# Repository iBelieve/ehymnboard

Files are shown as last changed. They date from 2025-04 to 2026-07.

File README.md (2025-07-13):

# eHymnBoard

A digital hymn board using e-ink screens. Designed and built by Michael Spencer and Christopher Spencer. First used in the Divine Service on Easter Sunday, A+D 2025.

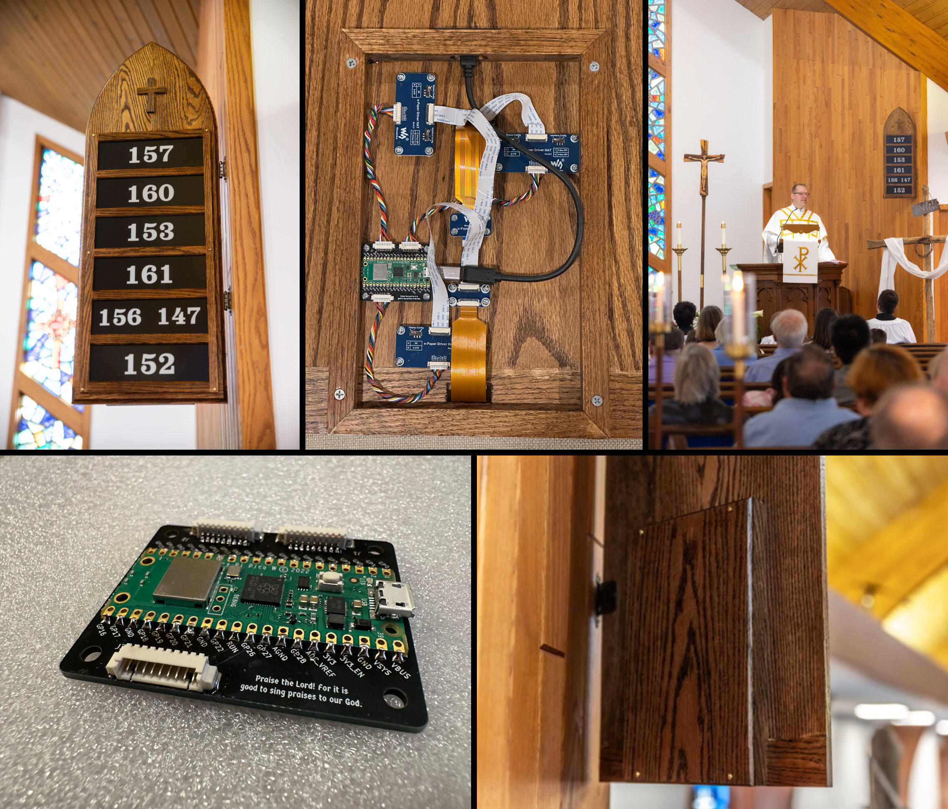
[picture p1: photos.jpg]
Photos of the hymn board


This was a really interesting opportunity to explore how we might leverage modern technology in an anti-technology, anti-screens way. Hymn boards are a beautiful contrast to the modern trend of putting big distracting glowing screens in the front of the sanctuary by directing the congregation to a hymnal, a physical book with a collection of beloved time-tested hymns, a book that belongs not just in the sanctuary but in the home for daily family devotions.

The e-ink is as minimally distracting as possible. The screens have no light and do not glow at all; the e-ink particles combined with a matte finish makes them look "real" and "physical" and not digital or screen-like.They are updated once before the service and are literally powered off for the entire duration of the service (due to its physical nature, e-ink "holds" its content without power).

Looking for other projects that explore how modern technology can enhance tradition? Check out the [St. Martin Luther Zimbelstern](https://github.com/cmspencer109/Zimbelstern) by Christopher Spencer.

### Project Parts and Tech Stack

**Device**

The on-device code is responsible for driving the e-ink screens and handling the network communication with the server.

- Raspberry Pi Pico W
- [3x Waveshare 13.3" E-Paper HAT (K)](https://www.waveshare.com/product/ai/displays/e-paper/13.3inch-e-paper-hat-k.htm)
- Pico SDK
- C++

**Server**

The web app and backend for the eHymnBoard project.

- Python 3
- Flask
- Tailwind CSS
- daisyUI

Code is deployed to a [Hetzner VPS](https://www.hetzner.com/cloud/) using [Dokku](https://dokku.com).

**PCB Designs**

Custom PCBs that add picoblade connectors to the Pi Pico for the e-ink screens to connect to.

- KiCad 6

**CAD Designs**

CAD designs for the actual wood hymn board, the routing jig, and 3D printed standoffs for mounting all the circuit boards in the enclosure.

[OnShape CAD designs](https://cad.onshape.com/documents/b7beeccbdc2f765f30134b80/w/63d45aaa309ee02d139aa6aa/e/1ed80022fc77088e67dab883)

### Suppliers

No affiliation or sponsorship, just good suppliers we found.

- [Waveshare](https://www.waveshare.com/) - E-ink screens
- [DigiKey](https://www.digikey.com/) - Electronic components
- [JLCPCB](https://jlcpcb.com/) - PCB manufacturing
- [Woodchucks Wood](https://woodchuckswood.com/) - Wood for the boards

### License

- The device code is licensed under the [GNU General Public License v3.0 or later](https://www.gnu.org/licenses/gpl-3.0.en.html).
- The server code is licensed under the [GNU Affero General Public License v3.0 or later](https://www.gnu.org/licenses/agpl-3.0.en.html).
- The CAD models and PCB designs are licensed under the [CERN Open Hardware License v2 - Strongly Reciprocal](https://gitlab.com/ohwr/project/cernohl/-/wikis/uploads/819d71bea3458f71fba6cf4fb0f2de6b/cern_ohl_s_v2.txt).

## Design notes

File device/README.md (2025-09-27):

# eHymnBoard Device Firmware

### Pico SDK

See documentation at https://datasheets.raspberrypi.com/pico/raspberry-pi-pico-c-sdk.pdf

Make sure you install the Raspberry Pi Pico SDK.

### WiFi Configuration

Copy `secrets.example.h` to `secrets.h` and replace the example config with one or more WiFi SSID and passphrase entries.

### Compiling

First create the build directory:

```sh
cmake -G Ninja -B build
```

Then cd into the build directory and run:

```sh
ninja
```

To flash the Pico:

```sh
picotool load -xf ehymnboard.elf
```

### Monitoring Output

You can monitor the serial output from the Pico using the included monitor script. It depends on `pyserial`, installable via pip. It will automatically detect the right serial device on macOS. Modify as needed for other platforms.

```sh
./monitor.py
```

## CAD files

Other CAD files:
hardware/KiCad-RP-Pico/SketchUp Model/Pico.skp

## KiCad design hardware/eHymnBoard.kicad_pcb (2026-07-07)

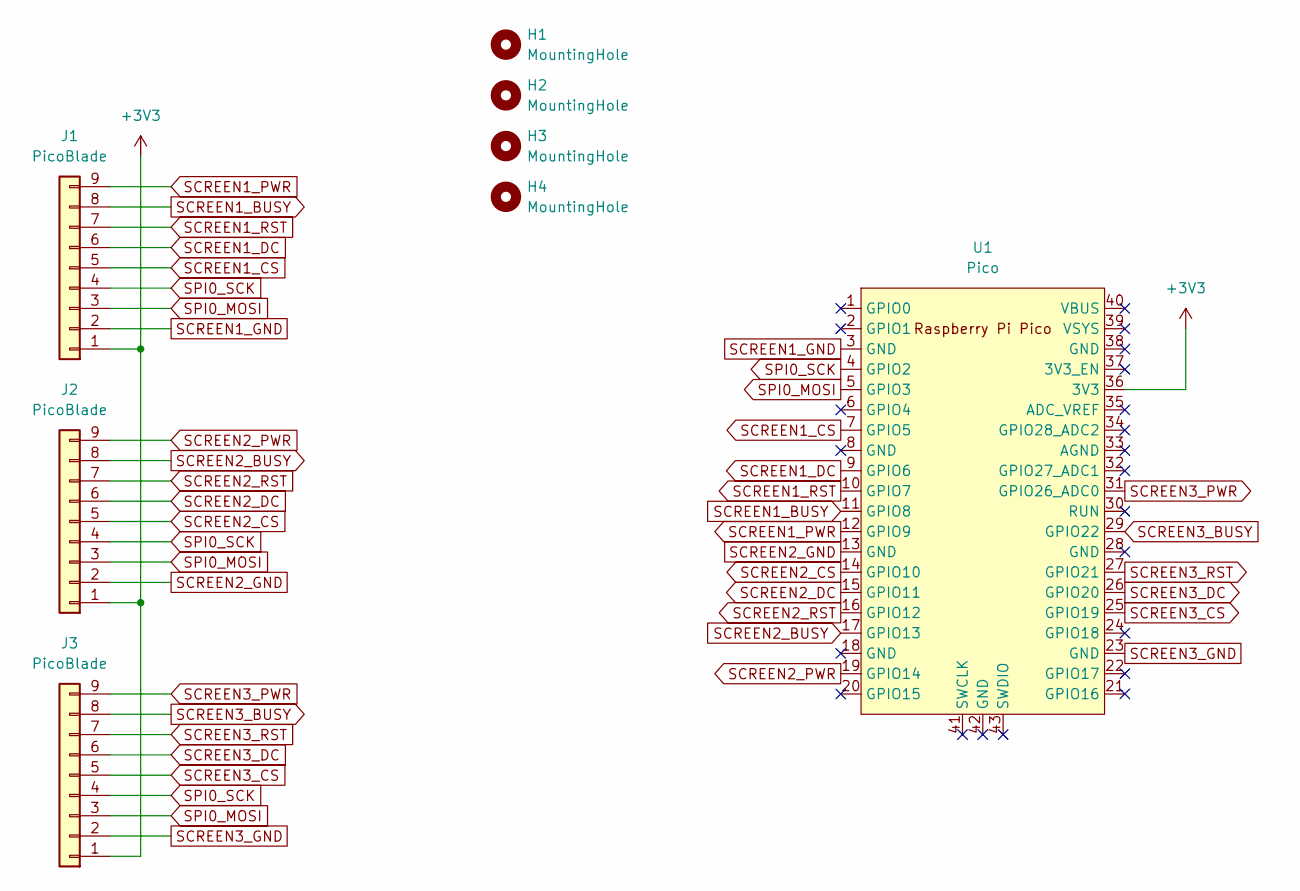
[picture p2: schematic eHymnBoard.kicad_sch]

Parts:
H1, H2, H3, H4: MountingHole; MountingHole_3mm
J1, J2, J3: PicoBlade; Molex_PicoBlade_53261-0971_1x09-1MP_P1.25mm_Horizontal
U1: Pico; RPi_Pico_SMD_TH

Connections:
+3V3: J1.1, J2.1, J3.1, U1.36 (3V3)
SCREEN1_BUSY: J1.8, U1.11 (GPIO8)
SCREEN1_CS: J1.5, U1.7 (GPIO5)
SCREEN1_DC: J1.6, U1.9 (GPIO6)
SCREEN1_GND: J1.2, U1.3 (GND)
SCREEN1_PWR: J1.9, U1.12 (GPIO9)
SCREEN1_RST: J1.7, U1.10 (GPIO7)
SCREEN2_BUSY: J2.8, U1.17 (GPIO13)
SCREEN2_CS: J2.5, U1.14 (GPIO10)
SCREEN2_DC: J2.6, U1.15 (GPIO11)
SCREEN2_GND: J2.2, U1.13 (GND)
SCREEN2_PWR: J2.9, U1.19 (GPIO14)
SCREEN2_RST: J2.7, U1.16 (GPIO12)
SCREEN3_BUSY: J3.8, U1.29 (GPIO22)
SCREEN3_CS: J3.5, U1.25 (GPIO19)
SCREEN3_DC: J3.6, U1.26 (GPIO20)
SCREEN3_GND: J3.2, U1.23 (GND)
SCREEN3_PWR: J3.9, U1.31 (GPIO26_ADC0)
SCREEN3_RST: J3.7, U1.27 (GPIO21)
SPI0_MOSI: J1.3, J2.3, J3.3, U1.5 (GPIO3)
SPI0_SCK: J1.4, J2.4, J3.4, U1.4 (GPIO2)

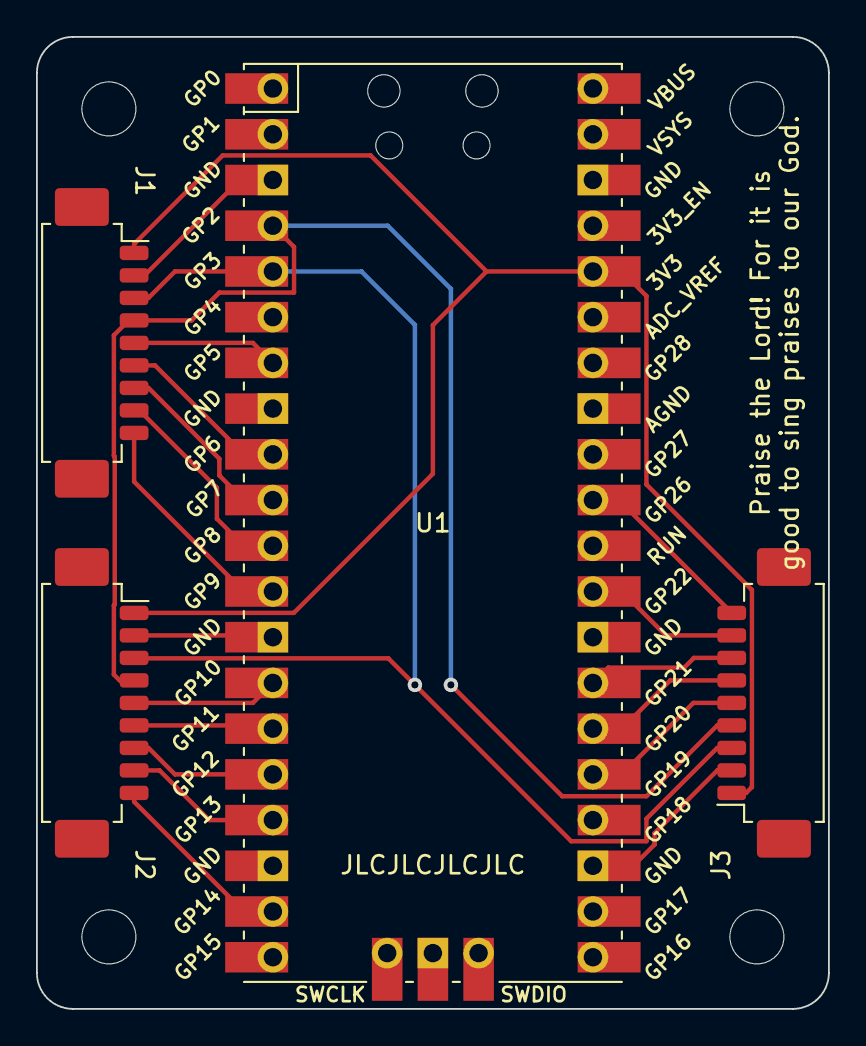
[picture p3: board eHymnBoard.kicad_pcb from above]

Board: 2 copper layers, 44.0 x 54.0 mm, 8 parts (0 on the bottom side), 21 nets.

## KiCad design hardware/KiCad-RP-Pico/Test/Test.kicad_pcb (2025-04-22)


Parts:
J1, J2: Conn_01x20; PinSocket_1x20_P1.00mm_Vertical
J3: Conn_01x03; PinSocket_1x03_P1.00mm_Vertical
U1: Pico; RPi_Pico_SMD_TH

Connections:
GND: J1.3, J1.8, J1.13, J1.18, J2.3, J2.13, J2.18, J3.2, U1.3 (GND), U1.8 (GND), U1.13 (GND), U1.18 (GND), U1.23 (GND), U1.28 (GND), U1.38 (GND), U1.42 (GND)
unnamed: J1.1, U1.1 (GPIO0)
unnamed: J1.2, U1.2 (GPIO1)
unnamed: J1.4, U1.4 (GPIO2)
unnamed: J1.5, U1.5 (GPIO3)
unnamed: J1.6, U1.6 (GPIO4)
unnamed: J1.7, U1.7 (GPIO5)
unnamed: J1.9, U1.9 (GPIO6)
unnamed: J1.10, U1.10 (GPIO7)
unnamed: J1.11, U1.11 (GPIO8)
unnamed: J1.12, U1.12 (GPIO9)
unnamed: J1.14, U1.14 (GPIO10)
unnamed: J1.15, U1.15 (GPIO11)
unnamed: J1.16, U1.16 (GPIO12)
unnamed: J1.17, U1.17 (GPIO13)
unnamed: J1.19, U1.19 (GPIO14)
unnamed: J1.20, U1.20 (GPIO15)
unnamed: J2.1, U1.40 (VBUS)
unnamed: J2.2, U1.39 (VSYS)
unnamed: J2.4, U1.37 (3V3_EN)
unnamed: J2.5, U1.36 (3V3)
unnamed: J2.6, U1.35 (ADC_VREF)
unnamed: J2.7, U1.34 (GPIO28_ADC2)
unnamed: J2.8, U1.33 (AGND)
unnamed: J2.9, U1.32 (GPIO27_ADC1)
unnamed: J2.10, U1.31 (GPIO26_ADC0)
unnamed: J2.11, U1.30 (RUN)
unnamed: J2.12, U1.29 (GPIO22)
unnamed: J2.14, U1.27 (GPIO21)
unnamed: J2.15, U1.26 (GPIO20)
unnamed: J2.16, U1.25 (GPIO19)
unnamed: J2.17, U1.24 (GPIO18)
unnamed: J2.19, U1.22 (GPIO17)
unnamed: J2.20, U1.21 (GPIO16)
unnamed: J3.1, U1.43 (SWDIO)
unnamed: J3.3, U1.41 (SWCLK)


Board: 2 copper layers, 43.0 x 65.0 mm, 4 parts (0 on the bottom side), 36 nets.

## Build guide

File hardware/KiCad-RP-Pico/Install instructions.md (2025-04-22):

# Install instructions

## 1. Copy the files locally

Copy the `RP-Pico Libraries` folder wherever you like on your computer.

## 2. Install the Raspberry Pi Pico board schema symbol

Use the `KiCad | Preferences | Manage Symbol Libraries...` command to manage the symbol library:



then select the global tab and click on the folder button:



navigate to the `RP-Pico Libraries` folder, select the `MCU_RaspberryPi_and_Boards.kicad_sym` file and open it:



et voilà, the first step is completed:



You can now close the symbol libraries manager window.

## 3. Install the Raspberry Pi Pico board footprint

You can use a similar approach to add the footprint to the footprint libraries manager, but I've found some issues that I've solved using the footprint editor, so here are the steps I suggest you to follow:

Open the footprint editor



wait for the footprints to load... then use the `File | Add Library` command:



confirm the `Global` choice:



and select the `MCU_RaspberriPi_and_Boards.pretty` folder (yes, the folder represent a footprint library on KiCad):



Now the library is installed on KiCad with the Raspberry Pi Pico footprint (double click on it to see it on the editor pane):



Don't close the windows as the next step start from here.

## 4. Install the Raspberry Pi Pico board footprint 3D visual

If not already open, open the the footprint editor

symbol library manager

double click on the `RPi_Pico_SMD_TH` footprint from the `MCU_RaspberriPi_and_Boards` library and then click on the `Footprint properties` icon:



In the footprint properties window, first select the `3D Settings` tab. Please note that the preview shows only the PCB board with the footprint added on step 3, without any 3D representation of the Raspberry Pi Pico board. Now click on the folder icon to add the 3D model:



Navigate to the `RP-Pico Libraries` folder, select the `Pico.wrl` file and wait until the model is shown in the right panel, then confirm with OK:



The model is already scaled and translated to match the footprint:



now close the `Footprint Properties` window, and the `Footprint Editor`, obviously saving the changes.

## Conclusion

Now that you've installed the schema and footprint and added the 3D model to the footprint, you can use the Raspberry Pi Pico board on your KiCad projects.

I've also added a test KiCad Project on the `Test` folder, that you can use to see an example of it.

Have fun!

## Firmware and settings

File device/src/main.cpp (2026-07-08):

/*
 * eHymnBoard device firmware
 * Copyright (C) 2025  Michael Spencer <sonrisesoftware@gmail.com>

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
 * You should have received a copy of the GNU General Public License
 * along with this program.  If not, see <https://www.gnu.org/licenses/>.
 */

#include "fetch_image.h"
#include "healthchecks.h"
#include "long_watchdog.h"
#include "pico/cyw43_arch.h"
#include "pico/stdlib.h"
#include "pico/unique_id.h"
#include "state.h"
#include "utils.h"
#include "waveshare.h"
#include "wifi.h"
#include <array>
#include <iostream>
#include <stdio.h>

// Refresh a single screen. On transient HTTP failures we just log and bail out
// for this iteration — the next loop will retry. The main loop tracks a "no
// success in too long" timeout to reset us if the network stays broken.
FetchImageResult refresh_screen(int screen_id, Waveshare13K &screen, std::string &etag)
{
    long_watchdog_update();

    printf("Refreshing screen %d\n", screen_id);
    auto ret = fetch_image(screen_id, etag);

    if (ret == FetchImageResult::NEW_IMAGE)
    {
        printf("New image for screen %d\n", screen_id);
        screen.init();
        screen.display(image_buffer);
        screen.shutdown();
    }
    else if (ret == FetchImageResult::NO_CHANGE)
    {
        printf("No change for screen %d\n", screen_id);
    }
    else
    {
        printf("Refreshing screen %d failed (ret=%d), will retry on next loop\n", screen_id, (int)ret);
    }

    return ret;
}

int main()
{
    stdio_init_all();

    long_watchdog_enable(60 /* seconds */);

    unique_board_id = get_unique_board_id();

    sleep_ms(3000);

    printf("eHymnboard starting...\n");
    printf("Pico SDK version: %s\n", PICO_SDK_VERSION_STRING);
    printf("Device ID: %s\n", unique_board_id.c_str());

    if (!flash_saved_state->is_valid())
    {
        printf("Flash saved state is invalid, resetting...\n");
        SavedState new_state;
        new_state.save();
    }
    else if (flash_saved_state->is_wrong_version())
    {
        printf("Flash saved state is wrong version (flash=%d, current=%d), resetting...\n", flash_saved_state->version,
               STATE_VERSION);
        SavedState new_state;
        new_state.save();
    }

    printf("Saved state version=%d, write count=%d\n", flash_saved_state->version, flash_saved_state->write_count);

    if (watchdog_caused_reboot())
    {
        printf("Rebooted due to watchdog timeout!\n");
    }

    setup_wifi();

    report_device_booted();

    SPI spi(spi0, SPI_1MHZ,
            2, // SCK pin
            3, // MOSI pin
            4  // MISO pin
    );

    Waveshare13K screen1(spi,
                         1, // Screen ID
                         9, // Power pin
                         5, // Chip Select pin
                         6, // Data/Command pin
                         7, // Reset pin
                         8  // Busy pin
    );
    std::string etag1 = flash_saved_state->etag1;

    Waveshare13K screen2(spi,
                         2,  // Screen ID
                         14, // Power pin
                         10, // Chip Select pin
                         11, // Data/Command pin
                         12, // Reset pin
                         13  // Busy pin
    );
    std::string etag2 = flash_saved_state->etag2;

    Waveshare13K screen3(spi,
                         3,  // Screen ID
                         26, // Power pin
                         19, // Chip Select pin
                         20, // Data/Command pin
                         21, // Reset pin
                         22  // Busy pin
    );
    std::string etag3 = flash_saved_state->etag3;

    printf("Screen 1 Etag: %s\n", etag1.c_str());
    printf("Screen 2 Etag: %s\n", etag2.c_str());
    printf("Screen 3 Etag: %s\n", etag3.c_str());

    // If every screen fetch fails for this long, give up and reboot to start
    // fresh. Picks up cleanly from a borked WiFi/DNS state without rebooting
    // on transient blips.
    constexpr int64_t NO_SUCCESS_REBOOT_TIMEOUT_US = 3LL * 60 * 1000 * 1000;

    uint32_t loop_count = 0;
    auto start_time = get_absolute_time();
    auto last_success_time = start_time;

    while (true)
    {
        loop_count++;
        auto uptime_s = absolute_time_diff_us(start_time, get_absolute_time()) / 1000000;
        printf("Refreshing screens (loop=%lu, uptime=%llds)...\n", (unsigned long)loop_count, uptime_s);

        auto r1 = refresh_screen(1, screen1, etag1);
        auto r2 = refresh_screen(2, screen2, etag2);
        auto r3 = refresh_screen(3, screen3, etag3);

        bool any_updated = (r1 == FetchImageResult::NEW_IMAGE) || (r2 == FetchImageResult::NEW_IMAGE) ||
                           (r3 == FetchImageResult::NEW_IMAGE);
        bool any_success =
            (r1 != FetchImageResult::ERROR) || (r2 != FetchImageResult::ERROR) || (r3 != FetchImageResult::ERROR);

        if (any_updated)
        {
            printf("One or more screens updated, saving state...\n");
            printf("- Screen 1 Etag: %s\n", etag1.c_str());
            printf("- Screen 2 Etag: %s\n", etag2.c_str());
            printf("- Screen 3 Etag: %s\n", etag3.c_str());

            SavedState new_state(flash_saved_state, etag1, etag2, etag3);
            new_state.save();

            printf("State saved to flash, %d total writes.\n", new_state.write_count);
        }

        if (any_success)
        {
            last_success_time = get_absolute_time();
        }
        else
        {
            auto since_success_s = absolute_time_diff_us(last_success_time, get_absolute_time()) / 1000000;
            printf("WARNING: no successful fetch for %llds\n", since_success_s);

            if (absolute_time_diff_us(last_success_time, get_absolute_time()) > NO_SUCCESS_REBOOT_TIMEOUT_US)
            {
                printf("All fetches have failed for >3 minutes, rebooting to recover\n");
                reset_pico();
            }
        }

        report_device_healthy();

        printf("Sleeping for 15 seconds...\n");
        sleep_ms(15000);
    }
}

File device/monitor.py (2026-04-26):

#!/usr/bin/env python3
import argparse
import os
import sys
import time
from datetime import datetime

import serial

BAUDRATE = 115200


def find_device():
    for device in os.listdir("/dev"):
        if device.startswith("tty.usbmodem"):
            return f"/dev/{device}"
    return None


def emit(line: str, log_file):
    stamped = f"{datetime.now().strftime('%H:%M:%S')} | {line}"
    print(stamped, flush=True)
    if log_file is not None:
        log_file.write(stamped + "\n")
        log_file.flush()


def device_loop(device: str, log_file):
    try:
        with serial.Serial(device, BAUDRATE, timeout=1) as ser:
            emit(f"Connected to {device}", log_file)
            while True:
                line = ser.readline().decode(errors="ignore").strip()
                if line:
                    emit(line, log_file)
    except serial.SerialException:
        emit(f"Lost connection to {device}, retrying in 1s...", log_file)
        time.sleep(1)


def main():
    parser = argparse.ArgumentParser(description="eHymnboard device serial monitor")
    parser.add_argument(
        "--log",
        metavar="PATH",
        help="Append timestamped output to this file in addition to stdout",
    )
    args = parser.parse_args()

    log_file = open(args.log, "a", buffering=1) if args.log else None

    try:
        while True:
            device = find_device()

            if device:
                device_loop(device, log_file)
            else:
                emit("Device not found, retrying in 1s...", log_file)
                time.sleep(1)
    except KeyboardInterrupt:
        # Graceful exit on Ctrl+C
        print("Exiting...")
    finally:
        if log_file is not None:
            log_file.close()


if __name__ == "__main__":
    main()

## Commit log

2025-04-22 Initial release for Easter 2025
    [Pico.skp, Test.kicad_pcb, Test.kicad_sch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]
2025-04-27 WiFi improvements
    - Track and connect to BSSID of specific WiFi result with strongest RSSI
    - Make 5 attempts every second to connect to a specific WiFi result
2025-05-11 Switch to sans serif font for better readability
2025-08-23 Fix spelling of Etag header - Cloudflare or something is changing it from ETag to Etag
    [main.cpp]
2025-08-23 Show recently connected devices on the admin web page
2025-08-27 Device code cleanup
2025-08-27 Set up watchdog to reboot after inactivity for 60 seconds
    [main.cpp]
2025-08-27 Ping healthchecks.io to track device uptime status
2025-09-27 Update monitor script to auto-detect USB serial device on macOS
2025-09-27 Add README.md to device project
2026-04-26 Fix lwIP race causing tcp_write PANIC; add HTTP error resilience
    In pico_cyw43_arch_lwip_threadsafe_background mode lwIP timers run in
    IRQ context, so calls into the lwIP API from the main thread must be
    bracketed with cyw43_arch_lwip_begin/end. Without that bracket,
    tcp_write inside httpc_get_file_dns can race with the background TCP
    timer and trip the "tcp_write: no pbufs on queue => both queues empty"
    assert in tcp_write_checks.
    Also stop calling reset_pico() on a single transient HTTP failure —
    RSTs and timeouts are normal background noise and don't justify a
    30-second-and-reboot cycle. Instead, retry on the next loop iteration
    and only reboot if every fetch has failed for more than 3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
    [main.cpp]
2026-07-07 Update hardware project to KiCad 10.0
    [eHymnBoard.kicad_pcb, eHymnBoard.kicad_sch]
2026-07-08 Fix clang-format violation in device main.cpp
    [main.cpp]
2026-07-08 Enable -Wall/-Wextra and clang-tidy for device; fix all findings
    Adds a WERROR cmake option (used by CI) and a .clang-tidy config
    (clang-analyzer, bugprone, performance), with clang-format and
    clang-tidy pinned as uv dev dependencies. Fixes the findings:
    - printf format mismatches for u32_t/size_t/enum class args (UB)
    - unbounded strcpy in SavedState replaced with snprintf
    - extra printf argument and unused variable in wifi.cpp
    - unused lwIP callback parameters marked [[maybe_unused]]
    - implicit int widening in 60s timeout constants
    - SavedState etags passed by const reference
    - unused width/height fields removed from Waveshare13K
    [main.cpp]
2026-07-08 Switch server to uv and Python 3.14
    Replaces pip-compile (requirements.in/txt) with a uv-managed
    pyproject.toml + uv.lock. The Docker image now uses python:3.14-slim
    with the uv binary copied from the official image and deps installed
    via uv sync --frozen.
2026-10-13 Add ruff and pyright; fix all lint and type errors
    ruff and pyright are pinned as uv dev dependencies (ruff also in
    device/ for monitor.py). Fixes:
    - device_id query params are str | None; get_device_name,
    ping_healthcheck, and update_device now handle missing device_id
    instead of silently recording bogus entries
    - unused watchdog_caused_reboot assignments removed
    - unused sys import removed from monitor.py
    - config/gunicorn.py reformatted
2026-10-13 Add CI workflows for device and server
    ci-device: clang-format check, pico-sdk build with warnings as
    errors, clang-tidy, and ruff for monitor.py. ci-server: uv lockfile
    check, ruff, pyright, and a Docker image build with GHA layer
    caching. Both are path-filtered to their directory and documented in
    CLAUDE.md along with how to run each check locally.
2026-11-13 Add Dependabot and build assets on Node 26 (#1)
    <!-- CURSOR_AGENT_PR_BODY_BEGIN -->
    Weekly Dependabot updates cover npm and Docker in server/, uv in server/ and device/, and GitHub Actions at the repo root. Minor and patch version updates are grouped into one pull request per ecosystem; major updates stay individual. New versions wait one day before a pull request is opened, which is the shortest cooldown Dependabot allows.
    The server image asset stage now uses node:26-slim, the current LTS line. CI reads server/.node-version and runs npm ci and the Tailwind build on that same major. The built stylesheet matches the Node 22 output. package.json has no lint script, so the new job does not li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

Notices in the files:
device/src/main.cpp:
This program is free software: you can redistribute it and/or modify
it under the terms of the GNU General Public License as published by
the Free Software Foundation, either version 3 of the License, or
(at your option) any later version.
